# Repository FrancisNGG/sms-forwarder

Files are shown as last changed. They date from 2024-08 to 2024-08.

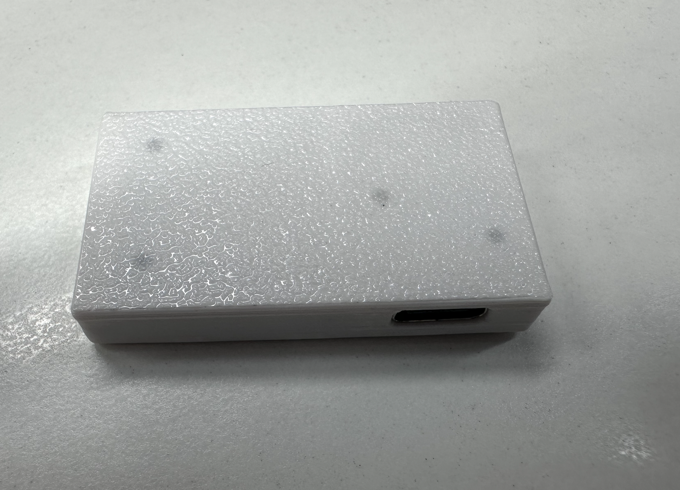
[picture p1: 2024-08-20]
image/截屏2024-08-20 13.53.17.png

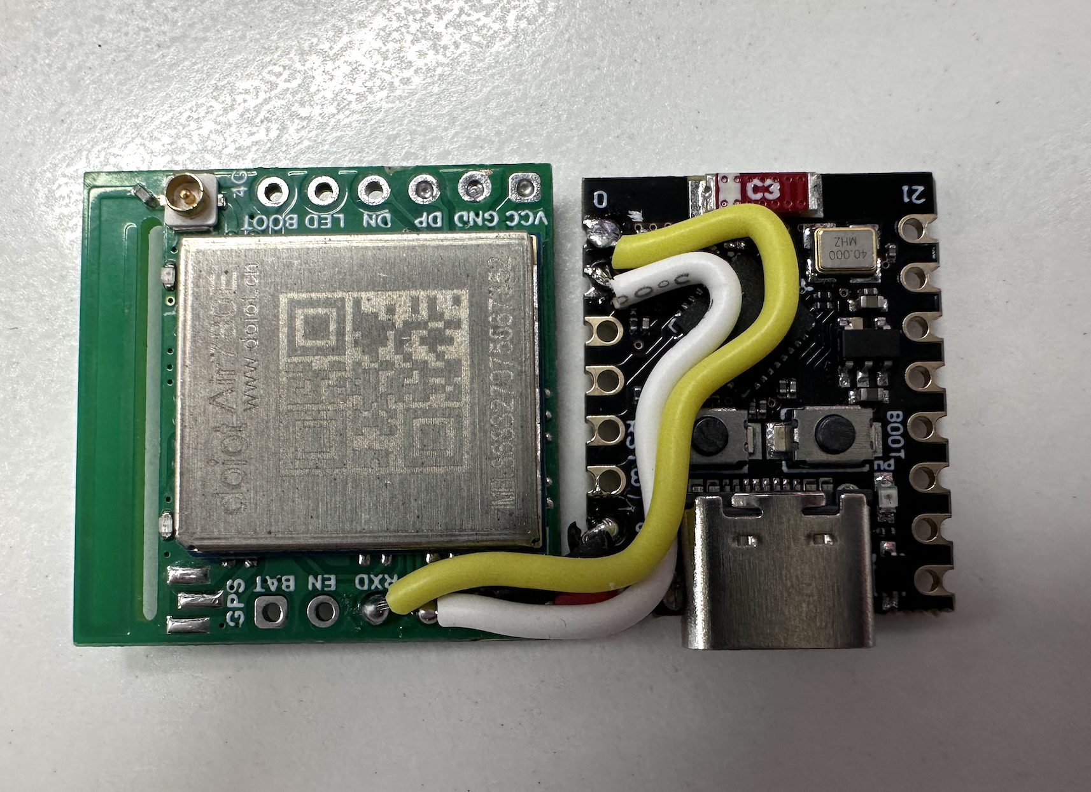
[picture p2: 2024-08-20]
image/截屏2024-08-20 13.53.03.png

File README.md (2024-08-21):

# sms-forwarder 现在成本也不低的短信转发器
ESP32C3 + Air780e 短信转发

## 修改内容
1. 使用 ESP32-C3 SuperMini + Air780E AT 模块
2. 增加了 Bark 推送
3. 增加了获取本机号码，并作为 Bark 分组推送
4. 修复了无法处理带换行符短信的问题
5. 修复了标题无法正常显示 +86 的问题
6. 增加了短信修改 Wi-Fi 和 CmdTag 功能

## 使用步骤
1. 模块接线

|Air780E|ESP32-C3|
|:-----:|:---:|
|  VCC  |  5V |
|  GND  |  GND |
|  TX |  1 |
|  RX |  0 |

2. 修改 util_notify.lua 添加你自己的推送，必须配置
3. 修改 util_wifi.lua 添加你自己的Wi-Fi，也可以不修改，通过短信发送Wi-Fi配置进行连接
4. 打印外壳
5. all done

## 短信指令

目前支持命令（[cmdTag]表示你的tag，可以理解为密码，默认1234）

```
C[cmdTag]REBOOT：重启

C[cmdTag]SEND[空格][手机号][空格][短信内容]：主动发短信

C[cmdTag]WIFI[空格][SSID][空格][PASSWORD]：修改 WIFI 连接

C[cmdTag]CMDTAG[空格][cmdTag]：修改 cmdTag

C[cmdTag]RESET：恢复出厂设置 (清空整个kv数据库)
```

如修改 Wi-Fi 连接，发送以下短信到插入的sim卡号码

`C1234WIFI ssid password`

## 关于本机号码获取
1. 国内 sim 卡一般可以正常获取本机号码
2. 如不能正常获取，可按以下步骤解决
- 使用 iPhone (Android未测试) 进入`设置-电话-本机号码`，进行手动输入保存后就能自动获取
- 编辑 `mian.lua` 中 `myNumber` 变量手动指定
- 号码格式为 `+8613800138000`
3. 不能正常获取本机号码的原因为：部分厂家并没有将本机号码写到 sim 卡

## 关于 GiffGaff 注册慢
1. 修改了逻辑，当识别到获取的号码非国内号码时，会优先手动注册到中国移动
2. 请确保能正常获取本机号码，或已手动设置本机号码

## 关于网络支持
1. 支持移动联通
2. 电信能注册成功，但无法收发短信

### 来自于以下项目稍作修改，感谢付出

>## 低成本短信转发器

>使用方法见[50元内自制短信转发器（Air780E+ESP32C3）](https://www.chenxublog.com/2022/10/28/19-9-sms-forwarding-air780e-esp32c3.html)

>## air780e-forwarder

>[Air700E / Air780E / Air780EP / Air780EPV 短信转发 来电通知](https://github.com/0wQ/air780e-forwarder)

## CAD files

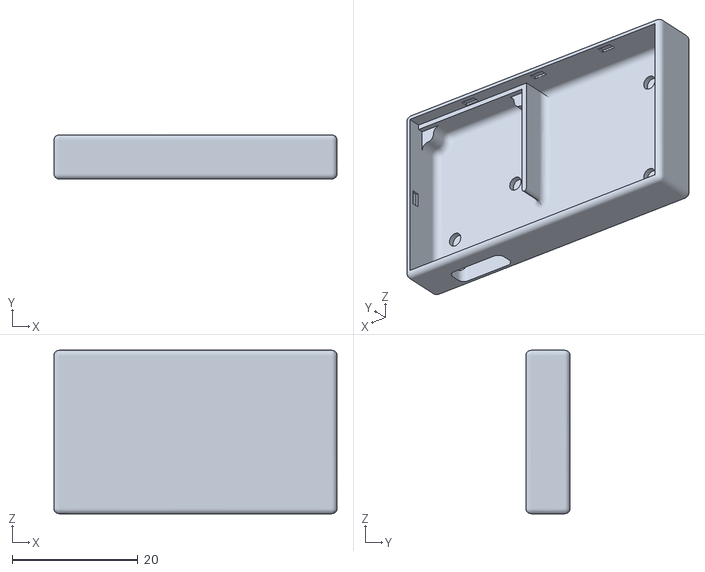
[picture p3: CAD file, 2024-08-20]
3d/bottom.stl
45.0 x 7.00 x 26.0

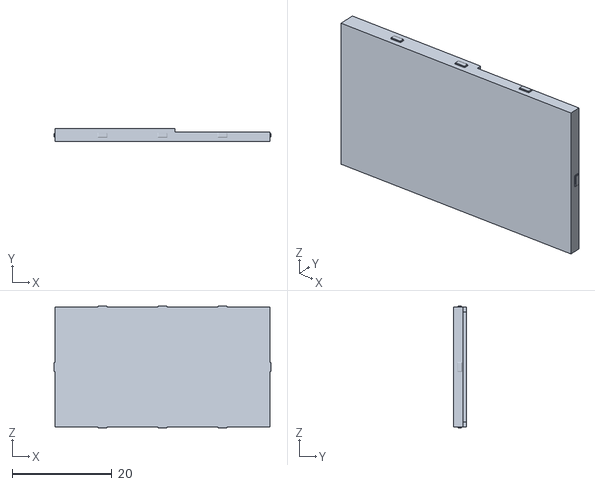
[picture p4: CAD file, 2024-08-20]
3d/top.stl
43.4 x 2.70 x 24.4

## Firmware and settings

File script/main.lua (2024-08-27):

-- LuaTools需要PROJECT和VERSION这两个信息
PROJECT = "sms_forwarder"
VERSION = "1.0.3"

log.info("main", PROJECT, VERSION)

-- 引入必要的库文件(lua编写), 内部库不需要require
sys = require("sys")
require("sysplus")

if wdt then
    -- 添加硬狗防止程序卡死，在支持的设备上启用这个功能
    wdt.init(9000) -- 初始化watchdog设置为9s
    sys.timerLoopStart(wdt.feed, 3000) -- 3s喂一次狗
end

-- 检查一下固件版本，防止用户乱刷
do
    local fw = rtos.firmware():lower() -- 全转成小写
    local ver, bsp = fw:match("luatos%-soc_v(%d-)_(.+)")
    ver = ver and tonumber(ver) or nil
    local r
    if ver and bsp then
        if ver >= 1004 and bsp == "esp32c3" then
            r = true
        end
    end
    if not r then
        sys.timerLoopStart(function()
            wdt.feed()
            log.info("警告",
                "固件类型或版本不满足要求，请使用esp32c3 v1004及以上版本固件。当前：" ..
                    rtos.firmware())
        end, 500)
    end
end

-- 本机号码 (一些国外卡获取不到号码，可以在此手动指定)
myNumber = "+8613800138000"

-- 运营商给的dns经常抽风，手动指定
socket.setDNS(nil, 1, "114.114.114.114")
socket.setDNS(nil, 2, "223.5.5.5")

-- 定时GC一下, 清理内存
sys.timerLoopStart(function()
    collectgarbage("collect")
end, 1000)

-- 初始化 fskv
log.info("main", "fskv.init", fskv.init())

-- 加载模块
lib_pdu = require("lib_pdu")
util_led = require("util_led")
util_air780e = require("util_air780e")
util_notify = require("util_notify")

local function clear_table(table)
    for i = 0, #table do
        table[i] = nil
    end
end

local function fix_time(time)
    return string.format("20%s-%s-%s %s:%s:%s %s", time:sub(1, 2), time:sub(4, 5), time:sub(7, 8), time:sub(10, 11),
        time:sub(13, 14), time:sub(16, 17), time:sub(18, 20))
end

local long_sms_buffer = {}

local function concat_and_send_long_sms(phone, time, sms)
    -- 拼接长短信
    local full_content = ""

    table.sort(sms, function(a, b)
        return a.id < b.id
    end)

    for _, v in ipairs(sms) do
        log.debug("long_sms", "message id: " .. v.id .. ", content: " .. v.data .. ", time: " .. v.time)
        full_content = full_content .. v.data
    end

    util_notify.add(phone, full_content)

    -- 清空缓冲区
    clear_table(sms)
end

local function clean_sms_buffer(phone, time, sms_id)
    if not long_sms_buffer[phone] then
        return
    end

    if not long_sms_buffer[phone][sms_id] then
        return
    end

    log.warn("sms", "long sms receive timeout from ", phone, time, sms_id)
    if #long_sms_buffer[phone][sms_id] > 0 then
        concat_and_send_long_sms(phone, time, long_sms_buffer[phone][sms_id])
        long_sms_buffer[phone][sms_id] = nil
    end
end

sys.taskInit(function()
    util_led.status = 1
    log.info("util_air780e", "sync at")
    -- 同步AT命令看通不通
    util_air780e.loopAT("AT", "AT_AT")

    -- 重启
    util_air780e.write("AT+RESET")
    -- 同步AT命令看通不通（确保重启完）
    util_air780e.loopAT("AT", "AT_AT")
    util_air780e.loopAT("ATE1", "AT_ATE1")

    -- 查询 Air780E 模块版本
    util_air780e.loopAT("AT+CGMR", "AT_AT")

    -- 关闭自动升级
    util_air780e.loopAT("AT+UPGRADE=\"AUTO\",0", "AT_UPGRADE")

    util_led.status = 3
    log.info("util_air780e", "check sim card")
    -- 检查下有没有卡
    local r = util_air780e.loopAT("AT+CPIN?", "AT_CPIN")
    if not r then
        log.error("util_air780e", "sim card is not inserted or failured! system will reboot after 2s!")
        util_led.status = 2
        sys.wait(2000)
        rtos.reboot()
        return
    end

    -- 配置一下参数
    log.info("util_air780e", "configrate")
    -- PDU模式
    util_air780e.loopAT("AT+CMGF=0", "AT_CMGF")
    -- 编码
    util_air780e.loopAT("AT+CSCS=\"UCS2\"", "AT_CSCS")
    -- 短信内容直接上报不缓存
    util_air780e.loopAT("AT+CNMI=2,2,0,0,0", "AT_CNMI")

    -- 获取本机号码
    log.info("util_air780e", "waiting for get the local phone number...")
    local num = util_air780e.loopAT("AT+CNUM", "AT_CNUM", 200, 5)
    if num then
        myNumber = num
        log.info("main", "gotta have number : ", myNumber)
    else
        log.info("main", "the phone number is not exist in sim card, use default number : ", myNumber)
    end

    -- 当获取的号码不是国内号码时，优先手动注册到中国移动 (主要针对 GiffGaff 在国内注册慢的问题)
    if string.sub(myNumber, 1, 3) ~= "+86" then
        log.info("main", "this number is not China mobile number, regedit to ChinaMobile first!")
        -- 参数 4 代表手自一体，当手动选择不成功时，会自动搜网
        util_air780e.write("AT+COPS=4,2,\"46000\"")
        sys.wait(10000)
    end

    -- 检查附着
    log.info("util_air780e", "wait for connection")
    while true do
        local r = util_air780e.loopAT("AT+CGATT?", "AT_CGATT", 1000)
        log.info("util_air780e", "connection status", r)
        if r then
            sys.publish("SIM_READY", r)
            break
        end
    end

    -- 查看所注册的运营商
    util_air780e.write("AT+COPS?")

    -- 初始化完成，发送通知
    util_notify.add("System",
        lib_pdu.utf8_ucs2("system is ready now! \nnumber:" .. myNumber .. "\nwaiting for new sms!"))

    util_led.status = 4
    log.info("util_air780e", "connected! wait sms")

    while true do
        collectgarbage("collect") -- 防止内存不足
        local _, phone, data, time, long, total, id, sms_id = sys.waitUntil("AT_CMT")
        time = fix_time(time)

        if long then -- 是长短信！
            log.info("util_air780e", "receive a long sms", phone, sms_id, id .. " / " .. total, time)
            -- 缓存，长短信存放处
            if not long_sms_buffer[phone] then
                long_sms_buffer[phone] = {}
            end
            if not long_sms_buffer[phone][sms_id] then
                long_sms_buffer[phone][sms_id] = {}
                sys.timerStart(clean_sms_buffer, 30 * 1000, phone, time, sms_id)
            end

            table.insert(long_sms_buffer[phone][sms_id], {
                id = id,
                data = data,
                time = time
            })

            if long_sms_buffer[phone][sms_id] and #long_sms_buffer[phone][sms_id] == total then
                concat_and_send_long_sms(phone, time, long_sms_buffer[phone][sms_id])
                long_sms_buffer[phone][sms_id] = nil
            end
        else
            log.info("util_air780e", "receive a sms", phone, time)
            util_notify.add(phone, data) -- 这次的短信
        end
    end
end)

-- 定时检查附着
sys.taskInit(function()
    sys.waitUntil("SIM_READY", 60 * 1000) -- 60s内等待附着，超时进入循环内执行重启
    while true do
        local r = util_air780e.loopAT("AT+CGATT?", "AT_CGATT", 1000)
        if r == false then
            log.info("util_air780e", "connected fail, system reboot after 2s")
            sys.wait(2000)
            rtos.reboot()
        else
            log.info("util_air780e", "connection status", r, "waiting for new sms!")
        end
        sys.wait(30 * 1000) -- 每 30s 检查附着
    end
end)

-- 用户代码已结束---------------------------------------------
-- 结尾总是这一句
sys.run()
-- sys.run()之后后面不要加任何语句!!!!!

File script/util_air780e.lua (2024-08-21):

local util_air780e = {}

local uartid = 1
local result = uart.setup(uartid, -- 串口id
115200, -- 波特率
8, -- 数据位
1 -- 停止位
)

-- 串口读缓冲区
local sendQueue = {}
-- 串口超时，串口准备好后发布的消息
local uartimeout, recvReady = 100, "UART_RECV_ID"
uart.on(uartid, "receive", function(id, len)
    local s = ""
    repeat
        s = uart.read(id, len)
        if #s > 0 then
            table.insert(sendQueue, s)
            sys.timerStart(sys.publish, uartimeout, recvReady)
        end
    until s == ""
end)

-- 发送AT指令
function util_air780e.write(s, notNeedCRLF)
    uart.write(uartid, s)
    log.info("util_air780e", "sent at", s)
    if notNeedCRLF then
        return
    end
    uart.write(uartid, "\r\n")
end

-- 向串口发送收到的字符串
sys.subscribe(recvReady, function()
    collectgarbage("collect") -- 防止内存不足
    -- 拼接所有收到的数据
    local s = table.concat(sendQueue)
    -- 串口的数据读完后清空缓冲区
    sendQueue = {}
    collectgarbage("collect") -- 防止内存不足

    s = s:gsub("\n", "\r")
    s = s:split("\r")
    collectgarbage("collect") -- 防止内存不足

    while #s > 0 do
        local line = table.remove(s, 1)
        log.info("uart", "line", line, line:toHex())
        if line == "AT" or line == "OK" then
            sys.publish("AT_AT")
            return
        end
        if line == "ATE1" then
            sys.publish("AT_ATE1")
            return
        end
        if line == "AT+UPGRADE=\"AUTO\",0" then
            sys.publish("AT_UPGRADE")
            return
        end
        if line == "AT+CMGF=0" then
            sys.publish("AT_CMGF")
            return
        end
        if line == "AT+CSCS=\"UCS2\"" then
            sys.publish("AT_CSCS")
            return
        end
        if line == "AT+CNMI=2,2,0,0,0" then
            sys.publish("AT_CNMI")
            return
        end
        if line == "> " then
            sys.publish("AT_SEND_SMS")
            return
        end
        local urc = line:match("^%+(%w+)")
        if urc then -- urc上报
            if urc == "CGATT" then -- 基站附着状态
                sys.publish("AT_CGATT", line:match("%+CGATT: *(%d)") == "1")
            elseif urc == "CNUM" then -- 获取到了本机号码
                sys.publish("AT_CNUM", line:match(',"+(%+%d+)"'))
            elseif urc == "CMT" then -- 来短信了
                local len = tonumber(line:match("%+CMT: *, *(%d+)"))
                repeat
                    local l = table.remove(s, 1)
                    if #l > 0 then
                        local phone, data, time, long, total, id, sms_id = lib_pdu.decodePDU(l, len)
                        log.info("sms", "recv", phone, time, long, sms_id, total, id, data)
                        sys.publish("AT_CMT", phone, data, time, long, total, id, sms_id)
                        break
                    end
                until #s == 0
            end
        else -- 其他命令解析
            -- log.info("uart", "check other cmd")
            local cmd = line:match("^AT%+(%w+)")
            if cmd then -- 命令回复
                if cmd == "CPIN" then -- 检查卡
                    -- log.info("uart", "CPIN found")
                    repeat
                        local l = table.remove(s, 1)
                        -- log.info("uart", "CPIN line",l)
                        if #l > 0 then
                            -- 错误码10=无卡 手册3.15章节
                            -- 错误码13=卡故障 手册3.15章节
                            if l:find("CME ERROR: 10") or l:find("CME ERROR: 13") then 
                                sys.publish("AT_CPIN", false)
                                return
                            else
                                sys.publish("AT_CPIN", true)
                                return
                            end
                        end
                    until #s == 0
                end
            end
        end
    end
end)

function util_air780e.loopAT(cmd, wait, loopTime, timeout)
    local start_time = os.time()
    while true do -- 检查AT状态
        util_air780e.write(cmd)
        local r, r1, r2, r3 = sys.waitUntil(wait, loopTime or 200)
        if r then
            log.info("util_air780e", "got recv", cmd)
            return r1, r2, r3
        end
        -- 检查是否超时
        if timeout and os.time() - start_time >= timeout then
            log.error("util_air780e", "loopAT timeout, cmd : ", cmd)
            return nil
        end
    end
end

return util_air780e

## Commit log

2024-08-20 v1.0.0
    1. 使用 ESP32-C3 SuperMini + Air780E AT 模块
    2. 增加了 Bark 推送
    3. 增加了获取本机号码，并作为 Bark 分组推送
    4. 修复了无法处理带换行符短信的问题
    5. 修复了标题无法正常显示 +86 的问题
    6. 增加了短信修改 Wi-Fi 和 CmdTag 功能
    [bottom.stl, top.stl]
2024-08-21 v1.0.1
    1. 修复国外卡获取不到本机号码时出错的问题
    2. 增加loopAT指令超时处理，避免死循环
    3. 修改CPIN判断卡是否存在的逻辑，部分卡返回 ERROR 属于其他状态，如卡繁忙，非无卡
    4. 国外卡优先注册到中国移动，注册失败后自动搜网，解决giffgaff搜网慢的问题
    5. 修复短信指令处理异常的问题
    [main.lua, util_air780e.lua]
2024-08-23 v1.0.2
    1. 增加定时检查附着，掉网自动重启
2024-08-27 v1.0.3
    1. 修改了定时检查附着的间隔时间为30s
    2. 添加 sim 卡尾号4位到 Bark 推送的标题
